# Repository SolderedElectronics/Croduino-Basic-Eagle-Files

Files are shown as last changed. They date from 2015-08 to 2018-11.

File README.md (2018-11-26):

# Croduino Basic Eagle Files
## Image
Croduino Basic image
[Croduino Basic(100009)](https://e-radionica.com/en/croduino-basic.html)

## Description and details
Croduino Basic is 100% Arduino compatible board made in EU(Croatia), created to promote Arduino culture in Croatia(well, it's named CROduino). Install Arduino software, plug it into USB and start DIY-ing!

It has even more analog inputs than Arduino Uno, features FTDI USB chip and built-in voltage regulator. The main difference from original Arduino and Croduino is size. Croduino is just 5cm x 3cm which makes it very easy to implement into projects. More:

- Atmega328 microcontroller(32kB flash, 2kB RAM, 1kB EEPROM)
- FTDI USB converter
- 22 I/O pins, 14 digital I/O, 6 PWM, 8 analog pins
- Size only 3 x 5cm (1.2 x 2 inch)
- LED light on the 13th pin
- Voltage regulator for possibility of external charging
- Made in Croatia
- Free lifetime technical support at techsupport@e-radionica.com

Microcontroller on-board is loaded with Arduino Optiboot bootloader.

## Repository content
This repo contains Cadsoft Eagle .sch and .brd files for Croduino Basic board. It also contains schematic in .pdf created from .sch Eagle file. 
Files have been arranged into folders for navigating between different versions of board. 
Tip: layer 200 shows top silkscreen and layer 208 should be bottom silkscreen. tParts and bParts is not used.

## Docs
- [Croduino Basic product page] (https://e-radionica.com/en/croduino-basic.html)
- [Croduino lessons - on croatian language] (https://vimeo.com/channels/croduino)

## Board versions
- v1.0 - inital internal version for protyping and internal projects. 
- v1.1 - production run version, some visual details changed.
- v1.2 - current version, never produced. Visual improved even more, few traces optimised. 

## License info
This product is open-source. Yay!
For any tech questions, contact us at techsupport@e-radionica.com
If you find an Issue, please open one at GitHub. If you can improve our product, fork us.

e-radionica.com Team.

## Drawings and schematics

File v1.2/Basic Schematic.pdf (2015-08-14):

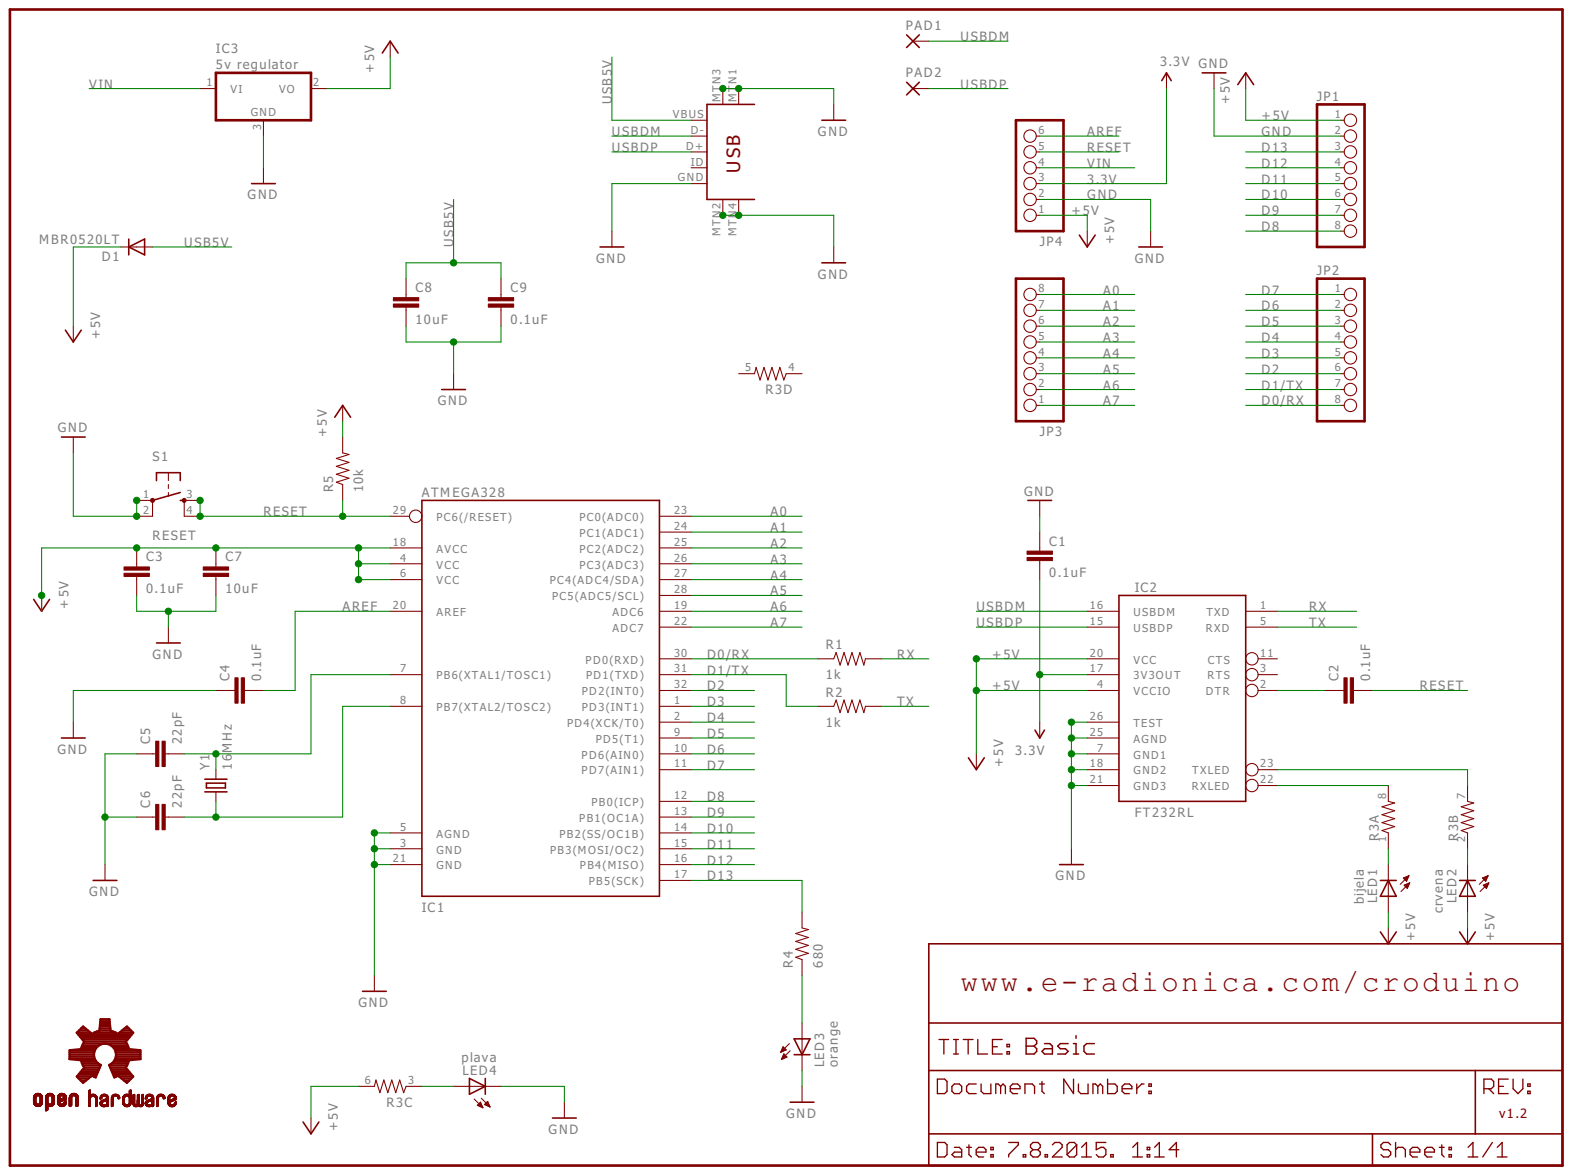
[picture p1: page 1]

v1.2 www.e-radionica.com/croduino

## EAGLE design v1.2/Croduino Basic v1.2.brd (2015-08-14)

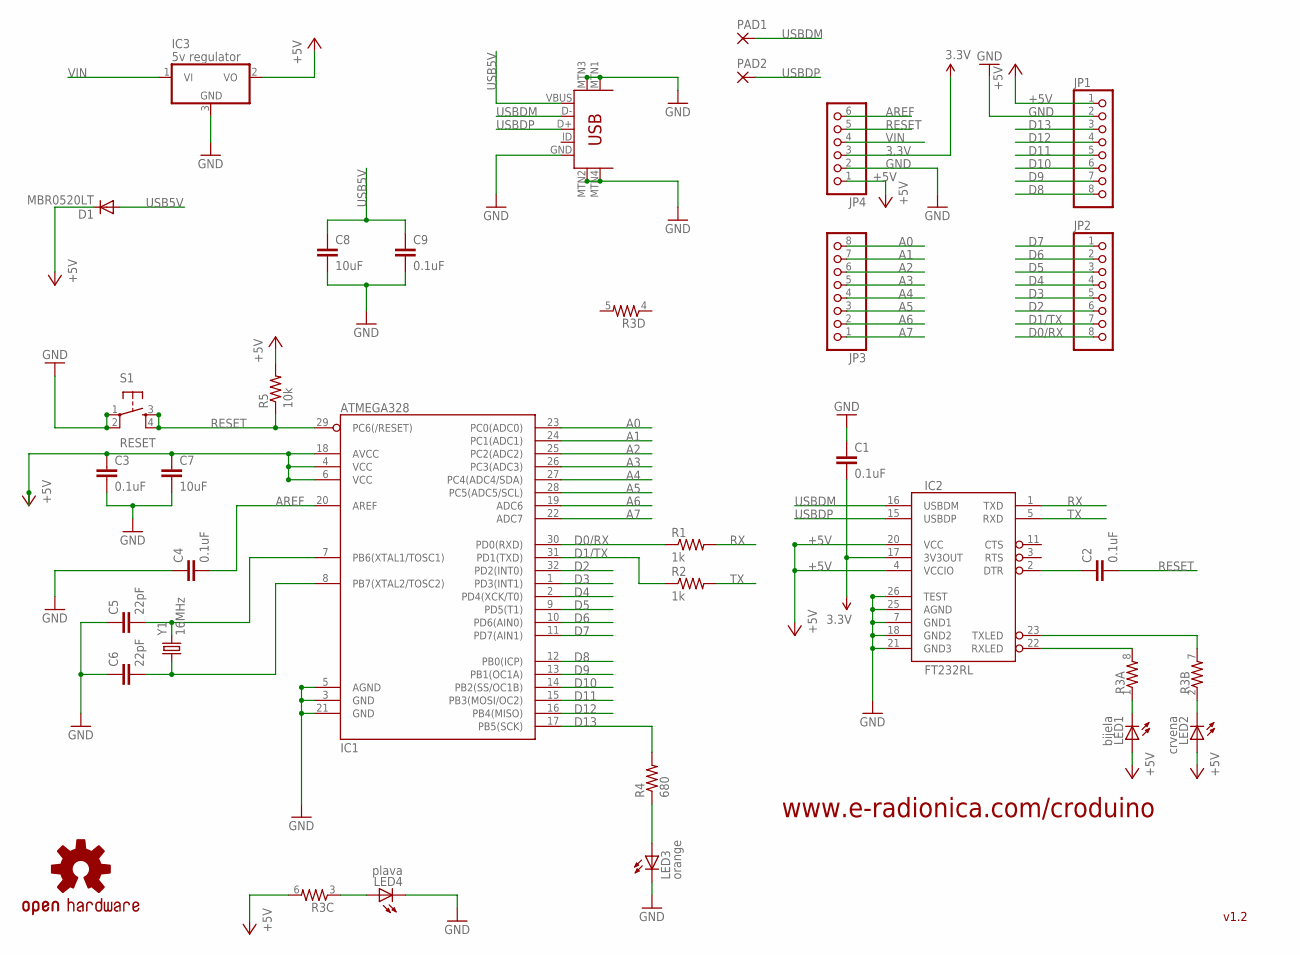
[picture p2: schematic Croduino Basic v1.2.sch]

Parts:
C1, C2, C3, C4, C9: 0.1uF; 0603-CAP
C5, C6: 22pF; 0603-CAP
C7, C8: 10uF; C3216
D1: MBR0520LT; SOD123
IC1: ATMEGA328; TQFP32-08
IC2: FT232RL; SSOP28DB
IC3: 5v regulator; TO252
JP1, JP2, JP3: PINHD-1X8BIG; 1X08-BIG
JP4: PINHD-1X6B; 1X06-BIG
LED1: bijela; CHIP-LED0805
LED2: crvena; CHIP-LED0805
LED3: orange; CHIP-LED0805
LED4: plava; CHIP-LED0805
PAD1, PAD2: SMD2; SMD1,27-2,54
R1, R2: 1k; 0603-RES
R3: RESISTOR-ARRAY0603-ARV; 0603-ARV
R4: 680; 0603-RES
R5: 10k; 0603-RES
S1: RESET; TACTILE_SWITCH_SMD
U1: USB-MINIB
U$5: OSHW-LOGOS; OSHW-LOGO-S
Y1: 16MHz; CRYSTAL-SMD-5X3

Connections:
3.3V: C1.2, IC2.17 (3V3OUT), JP4.3
+5V: C3.1, C7.1, D1.C, IC1.4 (VCC), IC1.6 (VCC), IC1.18 (AVCC), IC2.4 (VCCIO), IC2.20 (VCC), IC3.2 (VO), JP1.1, JP4.1, LED1.A, LED2.A, R3.6 (2), R5.2
A0: IC1.23 (PC0(ADC0)), JP3.8
A1: IC1.24 (PC1(ADC1)), JP3.7
A2: IC1.25 (PC2(ADC2)), JP3.6
A3: IC1.26 (PC3(ADC3)), JP3.5
A4: IC1.27 (PC4(ADC4/SDA)), JP3.4
A5: IC1.28 (PC5(ADC5/SCL)), JP3.3
A6: IC1.19 (ADC6), JP3.2
A7: IC1.22 (ADC7), JP3.1
AREF: C4.2, IC1.20 (AREF), JP4.6
CRYSTAL1: C5.2, IC1.7 (PB6(XTAL1/TOSC1)), Y1.3 (2)
CRYSTAL2: C6.2, IC1.8 (PB7(XTAL2/TOSC2)), Y1.1
D0/RX: IC1.30 (PD0(RXD)), JP2.8, R1.1
D1/TX: IC1.31 (PD1(TXD)), JP2.7, R2.1
D2: IC1.32 (PD2(INT0)), JP2.6
D3: IC1.1 (PD3(INT1)), JP2.5
D4: IC1.2 (PD4(XCK/T0)), JP2.4
D5: IC1.9 (PD5(T1)), JP2.3
D6: IC1.10 (PD6(AIN0)), JP2.2
D7: IC1.11 (PD7(AIN1)), JP2.1
D8: IC1.12 (PB0(ICP)), JP1.8
D9: IC1.13 (PB1(OC1A)), JP1.7
D10: IC1.14 (PB2(SS/OC1B)), JP1.6
D11: IC1.15 (PB3(MOSI/OC2)), JP1.5
D12: IC1.16 (PB4(MISO)), JP1.4
D13: IC1.17 (PB5(SCK)), JP1.3, R4.2
GND: C1.1, C3.2, C4.1, C5.1, C6.1, C7.2, C8.2, C9.2, IC1.3 (GND), IC1.5 (AGND), IC1.21 (GND), IC2.7 (GND1), IC2.18 (GND2), IC2.21 (GND3), IC2.25 (AGND), IC2.26 (TEST), IC3.3 (GND), JP1.2, JP4.2, LED3.C, LED4.C, S1.1, S1.2, U1.GND, U1.MTN1 (MTN2), U1.MTN2 (MTN3), U1.MTN3 (MTN1), U1.MTN4
unnamed: LED1.C, R3.1
unnamed: LED2.C, R3.2 (1)
unnamed: C2.1, IC2.2 (DTR)
unnamed: LED3.A, R4.1
unnamed: LED4.A, R3.3 (1)
RESET: C2.2, IC1.29 (PC6(/RESET)), JP4.5, R5.1, S1.3, S1.4
RX: IC2.1 (TXD), R1.2
RXLED: IC2.22 (RXLED), R3.8 (2)
TX: IC2.5 (RXD), R2.2
TXLED: IC2.23 (TXLED), R3.7 (2)
USB5V: C8.1, C9.1, D1.A, U1.VBUS
USBDM: IC2.16 (USBDM), PAD1.1, U1.D-
USBDP: IC2.15 (USBDP), PAD2.1, U1.D+
VIN: IC3.1 (VI), JP4.4

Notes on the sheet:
v1.2
www.e-radionica.com/croduino

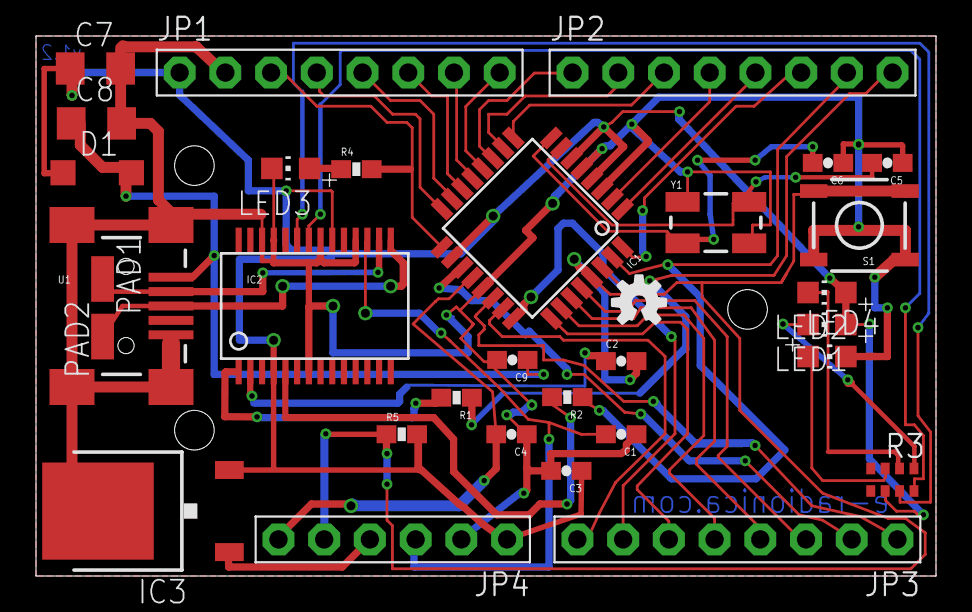
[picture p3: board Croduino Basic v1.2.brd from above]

Board: 2 copper layers, 50.0 x 30.0 mm, 35 parts (0 on the bottom side), 42 nets.

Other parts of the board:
U$1: CRODUINO_BASIC2
U$2: MADE-IN-CROATIA
U$4: UTICNICA3MM

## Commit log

2015-08-14 Added Eagle files and .pdf Schematic
    [Croduino Basic v1.2.brd, Croduino Basic v1.2.sch]
2015-08-24 Updated Readme and recreated Eagle files
    [Croduino Basic v1.2.brd, Croduino Basic v1.2.sch]

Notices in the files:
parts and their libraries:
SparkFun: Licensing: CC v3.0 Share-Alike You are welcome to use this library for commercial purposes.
